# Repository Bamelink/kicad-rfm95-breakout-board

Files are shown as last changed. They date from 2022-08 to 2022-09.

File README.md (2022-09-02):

# KiCad_RFM95_Breakout_Board

## Project Information
This project is a PCB containing the RFM95 868MHz LoRa Chip and a low power STM32L053R8T6 microprocessor.

**CAREFUL:** Neither the schematic, nor the pcb layout has been validated! Please check yourself before using / producing this!

## Things to change for Rev 2.0:
- Make SWD connecter to 2.54mm so Jumpers can fit.
- Get USB to work or better use a USB to UART bridge for Serial communication via USB and programming

## Exporting for JLCPCB
### Generate Files
Open KiCad. In the PCB view, click on File -> Plot -> Generate Drill Files...\
Make sure the Output directory is "gerber/"\
Click on Generate Drill Files and Generate Map files, close the window and click on Plot.\
Then under File -> Fabrication Output -> Footprint Position, check to box to exclude all throughole components and generate the position file.\
In the schematics view, click on Tools -> Generate BOM, select the first option and generate.
### Convert files
JLCPCB uses another header than KiCad. To change the files accordingly, install [this tool](https://github.com/matthewlai/JLCKicadTools) by executing:
```bash
pip install git+https://github.com/matthewlai/JLCKicadTools
```
Move the position file from the geber folder to the main project folder, open a command prompt and execute:
```bash
jlc-kicad-tools .
```
Zip the gerber folder and now you have the new files ready for JLCPCB.

# HINT
The CPW signal trace of the RFM Chip to is set to 50+5% Ohms impedance for FR4 material and 1.6 mm board thickness. The distance between signal and GND top plane is set to 0.2 mm.
Use e.g. [ CPW impedance calulator](https://chemandy.com/calculators/coplanar-waveguide-with-ground-calculator.htm) for calulate the impedance.

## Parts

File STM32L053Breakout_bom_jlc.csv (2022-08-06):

Comment | Designator | Footprint | LCSC Part #
22u | C100,C101 | C_0603_1608Metric | C59461
10u | C200,C700 | C_0603_1608Metric | C96446
100n | C201,C202,C203,C204,C400,C401,C402,C500,C701,C702,C801 | C_0402_1005Metric | C307331
1u | C205,C206,C800 | C_0603_1608Metric | C15849
10n | C207 | C_0402_1005Metric | C15195
10p | C501,C502 | C_0402_1005Metric | C32949
GREEN | D100,D400,D401 | LED_0603_1608Metric | C434420
BLUE | D402 | LED_0603_1608Metric | C375446
RED | D403 | LED_0603_1608Metric | C389517
100R | FB100 | L_0603_1608Metric | C96995
120R | FB200 | L_0603_1608Metric | C14709
ARM 10pin | J5 | PinHeader_2x05_P1.27mm_Vertical | C239059
USB_B_Micro | J100 | USB_Micro-B_Amphenol_10118194_Horizontal | C132563
Male Pinheader 1x20 | J300,J301 | PinHeader_1x20_P2.54mm_Vertical | C50981
1k5 | R100 | R_0603_1608Metric | C22843
1k | R400,R401,R402,R403 | R_0603_1608Metric | C21190
10k | R404,R405,R406,R500 | R_0603_1608Metric | C25804
SW_Push | SW400,SW401,SW402 | SW_SPST_B3U-1000P | C231329
Reset_Switch | SW500 | SW_SPST_B3U-1000P | C231329
BOOT0_Switch | SW501 | SW_E-Switch_EG1224_SPDT_Angled | C273395
AMS1117-3.3 | U100 | SOT-223-3_TabPin2 | C6186
STM32L053R8T6 | U500 | LQFP-64_10x10mm_P0.5mm | C79207
RFM95W-868S2 | U600 | HOPERF_RFM9XW_SMD | C2844472
LIS2HH12 | U700 | LGA-12_2x2mm_P0.5mm | C221446
L80-R | U800 | Quectel_L80-R | C133488
Crystal_GND24 | Y500 | Crystal_SMD_3225-4Pin_3.2x2.5mm | C112972

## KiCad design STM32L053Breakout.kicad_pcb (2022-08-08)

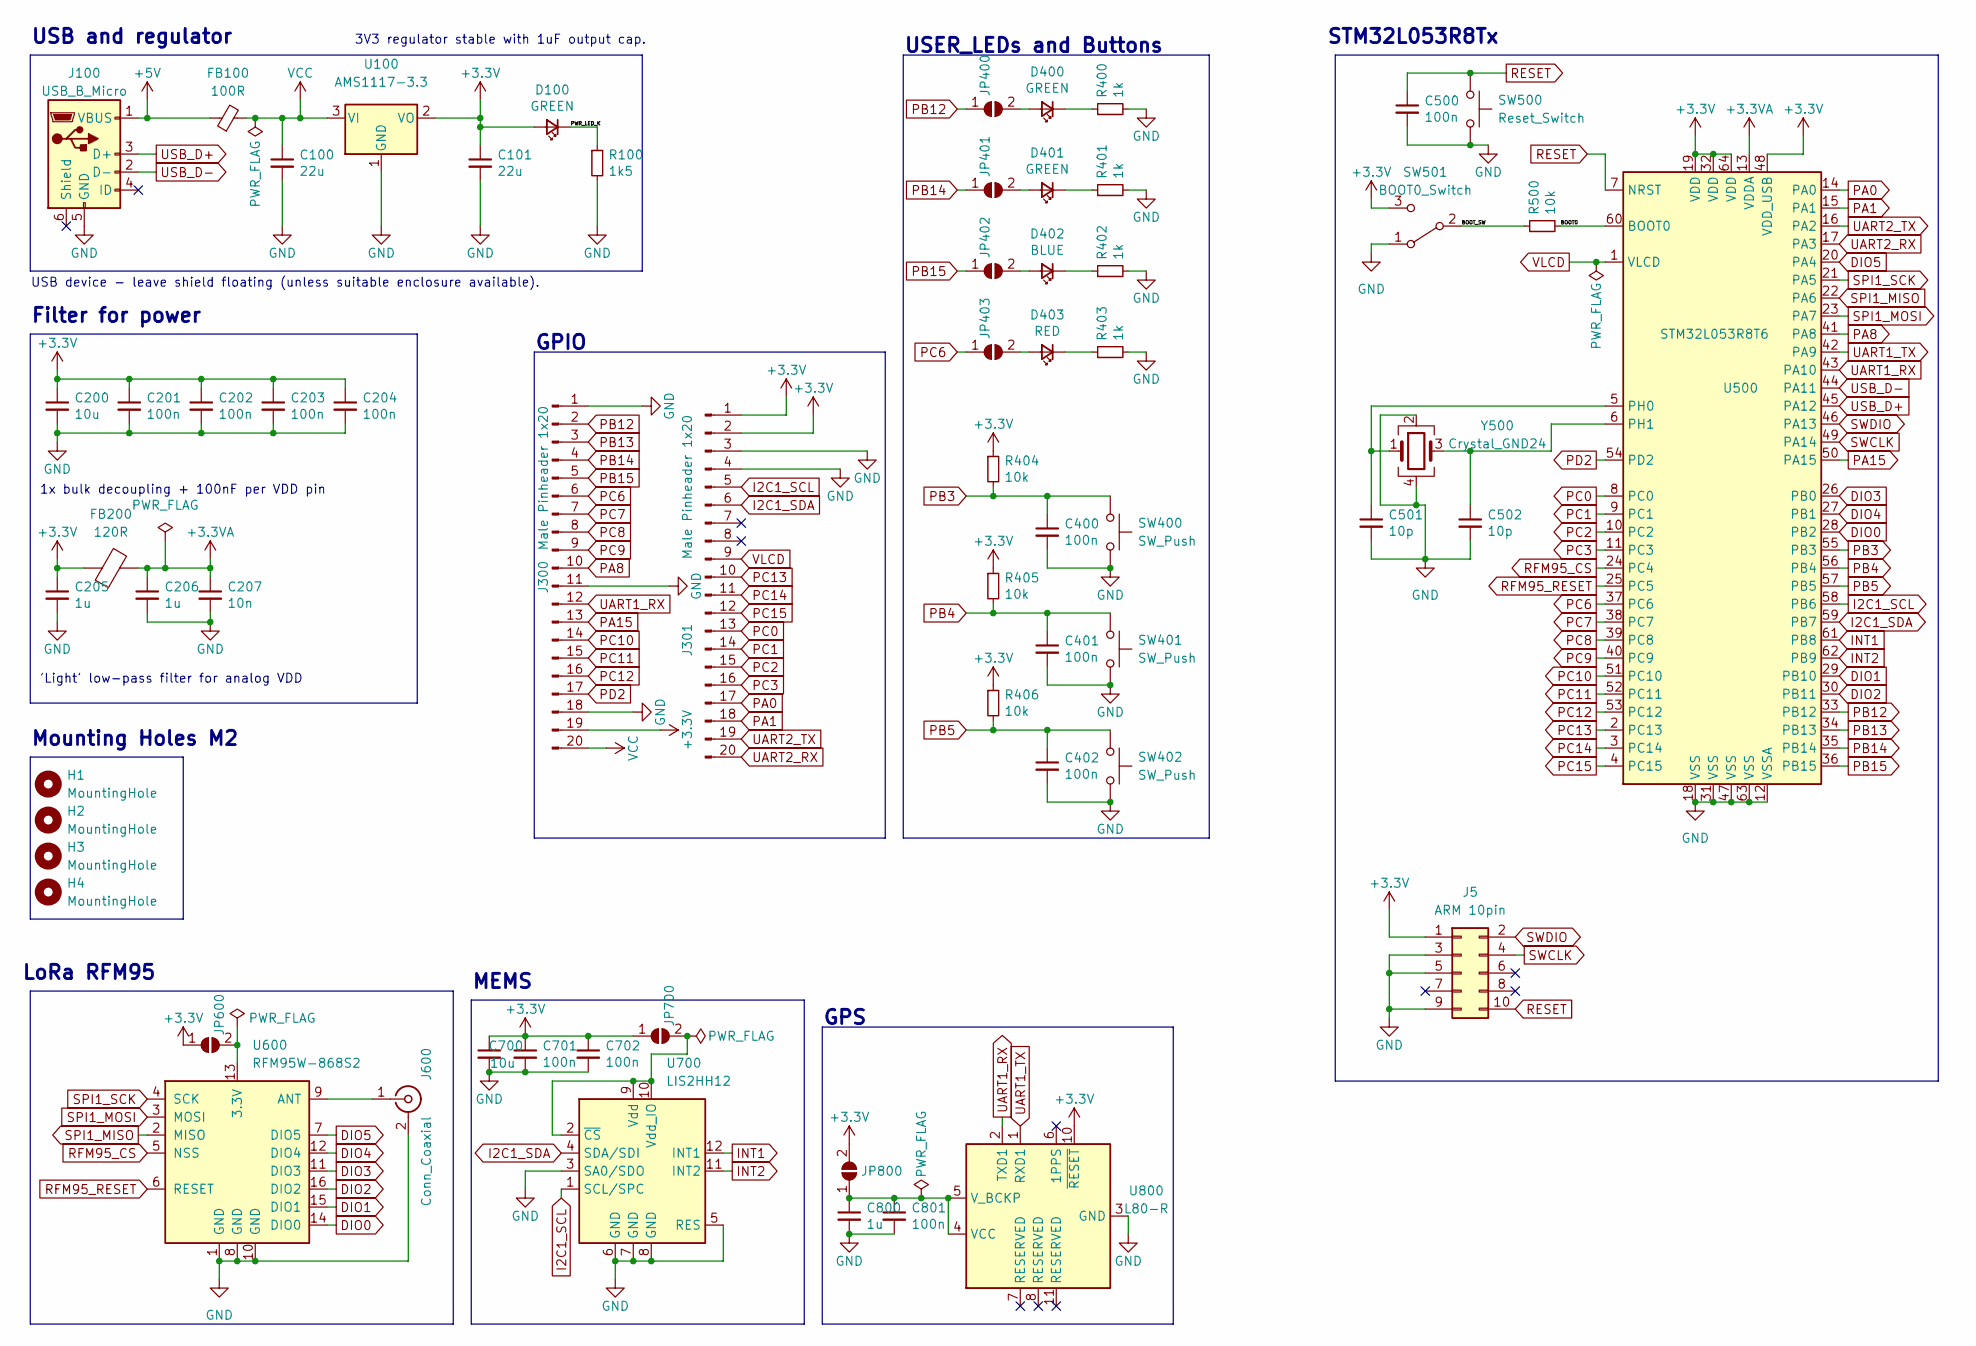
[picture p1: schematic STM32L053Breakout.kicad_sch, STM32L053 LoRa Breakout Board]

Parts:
C100, C101: 22u; C_0603_1608Metric; LCSC Part # C59461
C200, C700: 10u; C_0603_1608Metric; LCSC Part # C96446
C201, C202, C203, C204, C400, C401, C402, C500, C701, C702, C801: 100n; C_0402_1005Metric; LCSC Part # C307331
C205, C206, C800: 1u; C_0603_1608Metric; LCSC Part # C15849
C207: 10n; C_0402_1005Metric; LCSC Part # C15195
C501, C502: 10p; C_0402_1005Metric; LCSC Part # C32949
D100, D400, D401: GREEN; LED_0603_1608Metric; LCSC Part # C434420
D402: BLUE; LED_0603_1608Metric; LCSC Part # C375446
D403: RED; LED_0603_1608Metric; LCSC Part # C389517
FB100: 100R; L_0603_1608Metric; LCSC Part # C96995
FB200: 120R; L_0603_1608Metric; LCSC Part # C14709
H1, H2, H3, H4: MountingHole; MountingHole_2.2mm_M2
J5: ARM 10pin; PinHeader_2x05_P1.27mm_Vertical; LCSC Part # C239059
J100: USB_B_Micro; USB_Micro-B_Amphenol_10118194_Horizontal; LCSC Part # C132563
J300, J301: Male Pinheader 1x20; PinHeader_1x20_P2.54mm_Vertical; LCSC Part # C50981
J600: Conn_Coaxial; SMA_Samtec_SMA-J-P-X-ST-EM1_EdgeMount
JP400, JP401, JP402, JP403, JP600, JP700, JP800: SolderJumper_2_Open; SolderJumper-2_P1.3mm_Open_Pad1.0x1.5mm
R100: 1k5; R_0603_1608Metric; LCSC Part # C22843
R400, R401, R402, R403: 1k; R_0603_1608Metric; LCSC Part # C21190
R404, R405, R406, R500: 10k; R_0603_1608Metric; LCSC Part # C25804
SW400, SW401, SW402: SW_Push; SW_SPST_B3U-1000P; LCSC Part # C231329
SW500: Reset_Switch; SW_SPST_B3U-1000P; LCSC Part # C231329
SW501: BOOT0_Switch; SW_E-Switch_EG1224_SPDT_Angled; LCSC Part # C273395
U100: AMS1117-3.3; SOT-223-3_TabPin2; LCSC Part # C6186
U500: STM32L053R8T6; LQFP-64_10x10mm_P0.5mm; LCSC Part # C79207
U600: RFM95W-868S2; HOPERF_RFM9XW_SMD; LCSC Part # C2844472
U700: LIS2HH12; LGA-12_2x2mm_P0.5mm; LCSC Part # C221446
U800: L80-R; Quectel_L80-R; LCSC Part # C133488
Y500: Crystal_GND24; Crystal_SMD_3225-4Pin_3.2x2.5mm; LCSC Part # C112972

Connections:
+3.3V: C101.1, C200.1, C201.1, C202.1, C203.1, C204.1, C205.1, C700.1, C701.1, C702.1, D100.2 (A), FB200.1, J5.1, J300.19, J301.1, J301.2, JP600.1 (A), JP700.1 (A), JP800.2 (B), R404.1, R405.1, R406.1, SW501.3 (C), U100.2 (VO), U500.19 (VDD), U500.32 (VDD), U500.48 (VDD_USB), U500.64 (VDD), U800.10 (~RESET)
+3.3VA: C206.1, C207.1, FB200.2, U500.13 (VDDA)
+5V: FB100.1, J100.1 (VBUS)
/BOOT0: R500.2, U500.60 (BOOT0)
/BOOT_SW: R500.1, SW501.2 (B)
/PWR_LED_K: D100.1 (K), R100.1
DIO0: U500.28 (PB2), U600.14 (DIO0)
DIO1: U500.29 (PB10), U600.15 (DIO1)
DIO2: U500.30 (PB11), U600.16 (DIO2)
DIO3: U500.26 (PB0), U600.11 (DIO3)
DIO4: U500.27 (PB1), U600.12 (DIO4)
DIO5: U500.20 (PA4), U600.7 (DIO5)
GND: C100.2, C101.2, C200.2, C201.2, C202.2, C203.2, C204.2, C205.2, C206.2, C207.2, C400.2, C401.2, C402.2, C500.2, C501.2, C502.2, C700.2, C701.2, C702.2, C800.2, C801.2, J5.3, J5.5, J5.9, J100.5 (GND), J300.1, J300.11, J300.18, J301.3, J301.4, J600.2 (Ext), R100.2, R400.2, R401.2, R402.2, R403.2, SW400.2, SW401.2, SW402.2, SW500.2, SW501.1 (A), U100.1 (GND), U500.12 (VSSA), U500.18 (VSS), U500.31 (VSS), U500.47 (VSS), U500.63 (VSS), U600.1 (GND), U600.8 (GND), U600.10 (GND), U700.3 (SA0/SDO), U700.5 (RES), U700.6 (GND), U700.7 (GND), U700.8 (GND), U800.3 (GND), U800.12 (GND), Y500.2, Y500.4
I2C1_SCL: J301.5, U500.58 (PB6), U700.1 (SCL/SPC)
I2C1_SDA: J301.6, U500.59 (PB7), U700.4 (SDA/SDI)
INT1: U500.61 (PB8), U700.12 (INT1)
INT2: U500.62 (PB9), U700.11 (INT2)
unnamed: C501.1, U500.5 (PH0), Y500.1
unnamed: C502.1, U500.6 (PH1), Y500.3
unnamed: C800.1, C801.1, JP800.1 (A), U800.4 (VCC), U800.5 (V_BCKP)
unnamed: D400.1 (K), R400.1
unnamed: D400.2 (A), JP400.2 (B)
unnamed: D401.1 (K), R401.1
unnamed: D401.2 (A), JP401.2 (B)
unnamed: D402.1 (K), R402.1
unnamed: D402.2 (A), JP402.2 (B)
unnamed: D403.1 (K), R403.1
unnamed: D403.2 (A), JP403.2 (B)
unnamed: J600.1 (In), U600.9 (ANT)
unnamed: JP600.2 (B), U600.13 (3.3V)
unnamed: JP700.2 (B), U700.2 (~CS), U700.9 (Vdd), U700.10 (Vdd_IO)
PA0: J301.17, U500.14 (PA0)
PA1: J301.18, U500.15 (PA1)
PA8: J300.10, U500.41 (PA8)
PA15: J300.13, U500.50 (PA15)
PB3: C400.1, R404.2, SW400.1, U500.55 (PB3)
PB4: C401.1, R405.2, SW401.1, U500.56 (PB4)
PB5: C402.1, R406.2, SW402.1, U500.57 (PB5)
PB12: J300.2, JP400.1 (A), U500.33 (PB12)
PB13: J300.3, U500.34 (PB13)
PB14: J300.4, JP401.1 (A), U500.35 (PB14)
PB15: J300.5, JP402.1 (A), U500.36 (PB15)
PC0: J301.13, U500.8 (PC0)
PC1: J301.14, U500.9 (PC1)
PC2: J301.15, U500.10 (PC2)
PC3: J301.16, U500.11 (PC3)
PC6: J300.6, JP403.1 (A), U500.37 (PC6)
PC7: J300.7, U500.38 (PC7)
PC8: J300.8, U500.39 (PC8)
PC9: J300.9, U500.40 (PC9)
PC10: J300.14, U500.51 (PC10)
PC11: J300.15, U500.52 (PC11)
PC12: J300.16, U500.53 (PC12)
PC13: J301.10, U500.2 (PC13)
PC14: J301.11, U500.3 (PC14)
PC15: J301.12, U500.4 (PC15)
PD2: J300.17, U500.54 (PD2)
RESET: C500.1, J5.10, SW500.1, U500.7 (NRST)
RFM95_CS: U500.24 (PC4), U600.5 (NSS)
RFM95_RESET: U500.25 (PC5), U600.6 (RESET)
SPI1_MISO: U500.22 (PA6), U600.2 (MISO)
SPI1_MOSI: U500.23 (PA7), U600.3 (MOSI)
SPI1_SCK: U500.21 (PA5), U600.4 (SCK)
SWCLK: J5.4, U500.49 (PA14)
SWDIO: J5.2, U500.46 (PA13)
UART1_RX: J300.12, U500.43 (PA10), U800.2 (TXD1)
UART1_TX: U500.42 (PA9), U800.1 (RXD1)
UART2_RX: J301.20, U500.17 (PA3)
UART2_TX: J301.19, U500.16 (PA2)
USB_D+: J100.3 (D+), U500.45 (PA12)
USB_D-: J100.2 (D-), U500.44 (PA11)
VCC: C100.1, FB100.2, J300.20, U100.3 (VI)
VLCD: J301.9, U500.1 (VLCD)

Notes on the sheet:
Mounting Holes M2
STM32L053R8Tx
USB and regulator
MEMS
GPIO
'Light' low-pass filter for analog VDD
1x bulk decoupling + 100nF per VDD pin
USB device - leave shield floating (unless suitable enclosure available).
LoRa RFM95
3V3 regulator stable with 1uF output cap.
Filter for power
GPS
USER_LEDs and Buttons

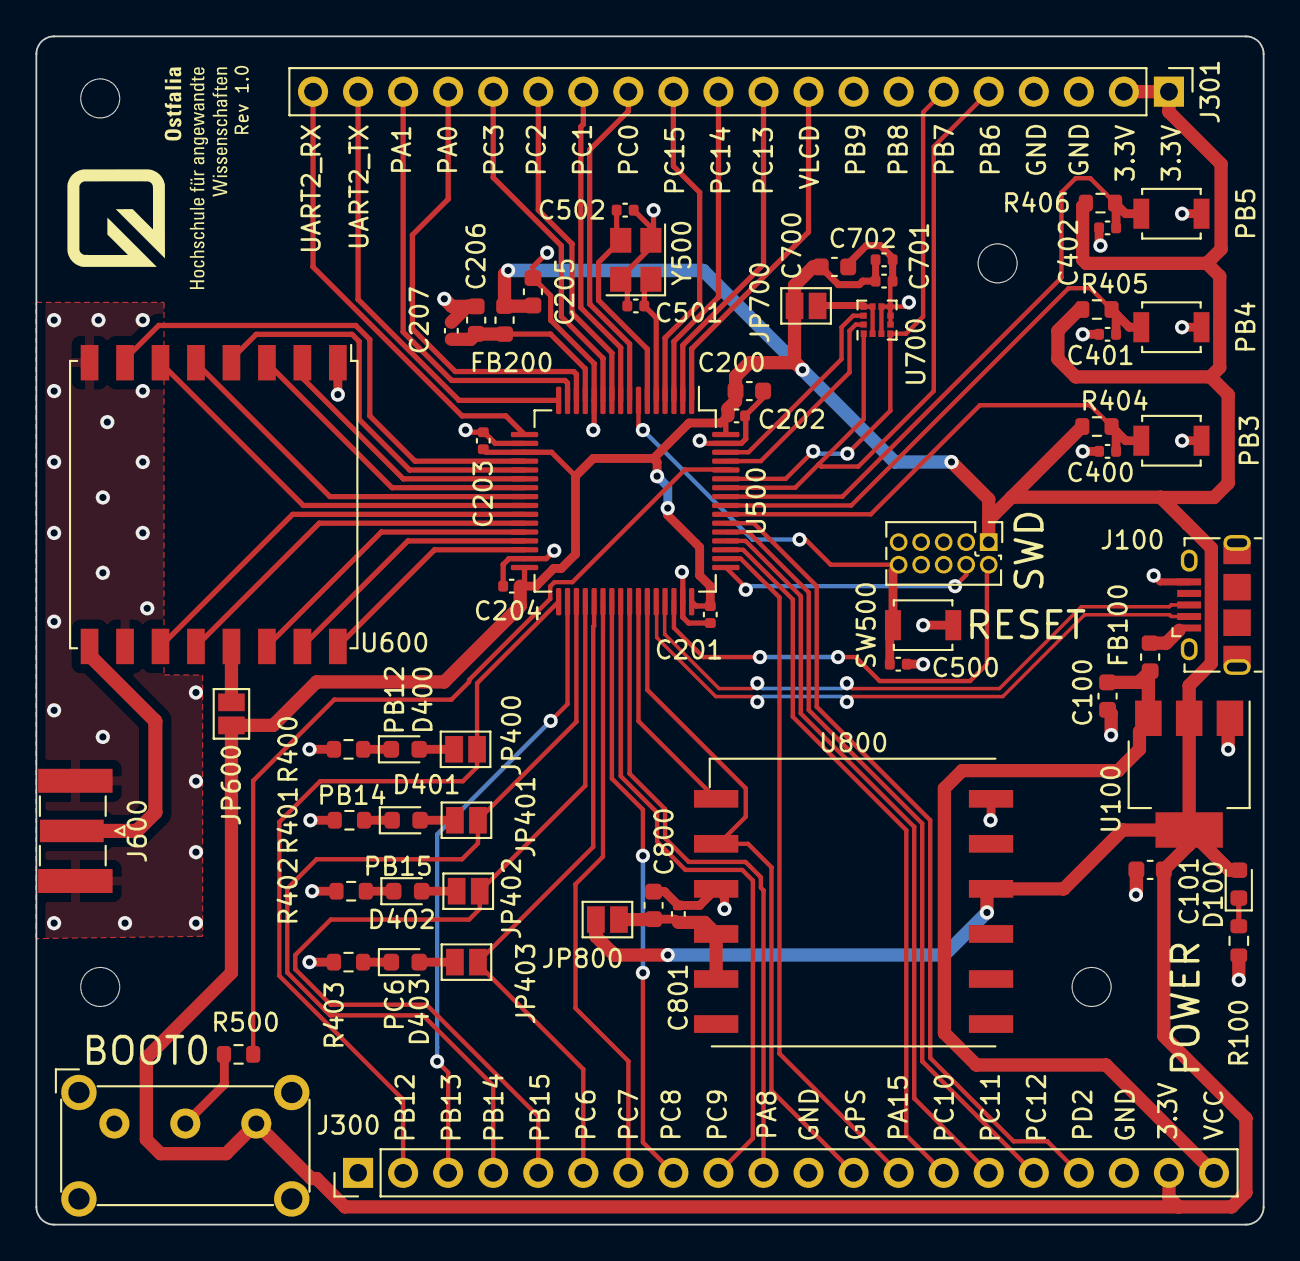
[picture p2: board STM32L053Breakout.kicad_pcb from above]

Board: 2 copper layers, 69.2 x 67.0 mm, 66 parts (0 on the bottom side), 73 nets.

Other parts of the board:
 : LOGO; ostfalia_logo_5.5mm
 #2: LOGO; ostfalia_logo_schrift_12.5mm

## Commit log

2022-06-28 Remove Top GND Layer
    [RFM_STM_Breakout.kicad_pcb]
2022-06-28 Change angles and 3.3V Rail
    [RFM_STM_Breakout.kicad_pcb, RFM_STM_Breakout.kicad_sch]
2022-06-28 impedance adjustment of the signal trace, improve GND conncetion, fix board border
    [RFM_STM_Breakout.kicad_pcb]
2022-07-05 Detachtable with GPS
    [RFM_STM_Breakout.csv, RFM_STM_Breakout.kicad_pcb, RFM_STM_Breakout.kicad_sch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]
2022-07-05 Remove old
    [RFM_STM_Breakout.csv, RFM_STM_Breakout.kicad_pcb, RFM_STM_Breakout.kicad_sch]
2022-07-05 Update USB Pullup (R already internal in STM32L0 processors)
    [RFM_STM_Breakout.kicad_pcb, RFM_STM_Breakout.kicad_sch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]
2022-07-09 add rfm signal out to CPW & add Logos
    [STM32L053Breakout.kicad_pcb]
2022-07-10 Change Keepout and add 3.3V Rail to RFM
    [STM32L053Breakout.kicad_pcb]
2022-07-26 Add sensor and change bom for GPS
    [STM32L053Breakout.kicad_pcb, STM32L053Breakout.kicad_sch]
2022-08-06 Change BOM for JLC
    [STM32L053Breakout-B_Cu.gbr, STM32L053Breakout-B_Mask.gbr, STM32L053Breakout-B_Paste.gbr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]
2022-08-08 Add Rev Number
    [STM32L053Breakout.kicad_pcb]
